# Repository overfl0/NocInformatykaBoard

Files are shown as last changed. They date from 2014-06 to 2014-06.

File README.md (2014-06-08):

Noc Informatyka Board
=====================

In this repository you'll find all the files related to the identifier given to every attendee of the Noc Informatyka^8 conference. You can find *[details]* here *(Polish)*.

This identifier was also a fully compatible Digispark clone.

Directories
===========

Schematics
----------

This directory holds the *[Eagle]* files used to create and produce the PCB for the identifier. The Eagle version that was used was 6.5.

Firmware
--------

This directory holds the micronucleus bootloader firmware that allows the badge to communicate with a PC and to upload sketches (programs) over the USB connector present on the board.

To upload a new firmware you either need to use an external HVSP programmer or use the virus-like firmware upgrade method.

#### Upload using an external HVSP programmer

Bear in mind that the microcontroller has its reset pin disabled. What this means is that regular ISP programmers (like USBasp) will not be able to program the board unless you reset the fuses with a HVSP programmer or something like *[Attiny fusebit Doctor]*.

```
make
make fuse
make flash
make disablereset
```

#### Upload using the virus-like method

This method has not been tested by us. **Use at your own risk!** See *upgrade* directory for details.

NocInformatyka2014
------------------

This directory holds the sketch preloaded on the badge. If for some reason you would like to revert to the original program, just upload this sketch to the board.

[eagle]:http://www.cadsoftusa.com/eagle-pcb-design-software/product-overview/?language=en
[attiny fusebit doctor]:http://www.instructables.com/id/AVR-Attiny-fusebit-doctor-HVSP/
[details]:http://nocinformatyka.pl/board/

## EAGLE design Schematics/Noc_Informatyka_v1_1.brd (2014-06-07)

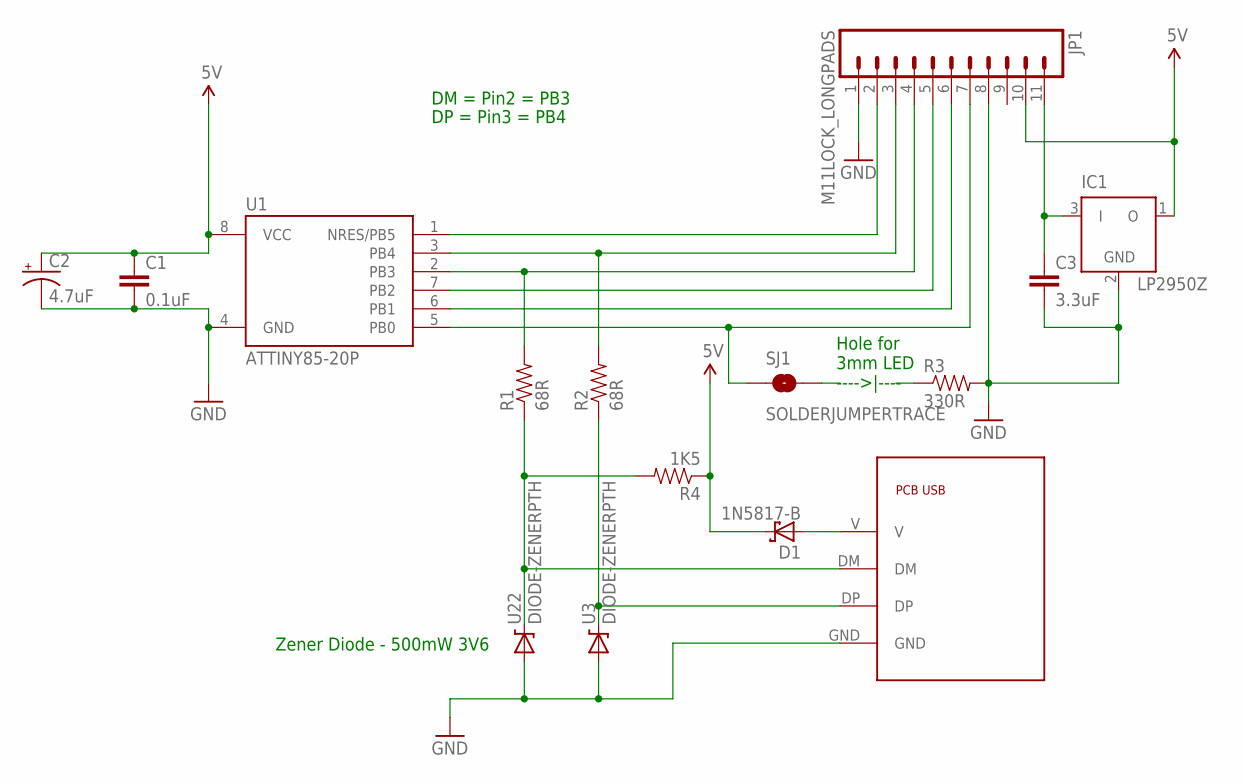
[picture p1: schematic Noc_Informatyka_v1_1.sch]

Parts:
C1: 0.1uF; CAP-PTH-SMALLEZ
C2: 4.7uF; CPOL-RADIAL-10UF-25V
C3: 3.3uF; CAP-PTH-5MM
D1: 1N5817-B; DO41-7.6
IC1: LP2950Z; TO92
JP1: M11LOCK_LONGPADS; 1X11_LOCK_LONGPADS
R1, R2: 68R; AXIAL-0.3EZ
R3: 330R; AXIAL-0.3EZ
R4: 1K5; AXIAL-0.3EZ
SJ1: SOLDERJUMPERTRACE; SJ_2S-TRACE
U1: ATTINY85-20P; PDIP08_300MIL
U3, U22: DIODE-ZENERPTH; DIODE-ZENER
U$1: PCB_USBNOBACK; PCB_USB

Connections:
5V: C1.1, C2.1 (+), D1.C, IC1.1 (O), JP1.10, R4.P$1 (1), U1.8 (VCC)
GND: C1.2, C2.2 (-), C3.2, IC1.2 (GND), JP1.1, JP1.8, R3.P$2 (2), U1.4 (GND), U3.P$2 (A), U22.P$2 (A), U$1.GND
unnamed: R1.P$1 (1), R4.P$2 (2), U22.P$1 (C), U$1.DM
unnamed: JP1.2, U1.1 (NRES/PB5)
unnamed: JP1.3, R2.P$2 (2), U1.3 (PB4)
unnamed: JP1.4, R1.P$2 (2), U1.2 (PB3)
unnamed: JP1.5, U1.7 (PB2)
unnamed: JP1.6, U1.6 (PB1)
unnamed: JP1.7, SJ1.1, U1.5 (PB0)
unnamed: C3.1, IC1.3 (I), JP1.11
unnamed: R2.P$1 (1), U3.P$1 (C), U$1.DP
unnamed: D1.A, U$1.V

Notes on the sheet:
DM = Pin2 = PB3
DP = Pin3 = PB4
Hole for 3mm LED ---->|----
Zener Diode - 500mW 3V6

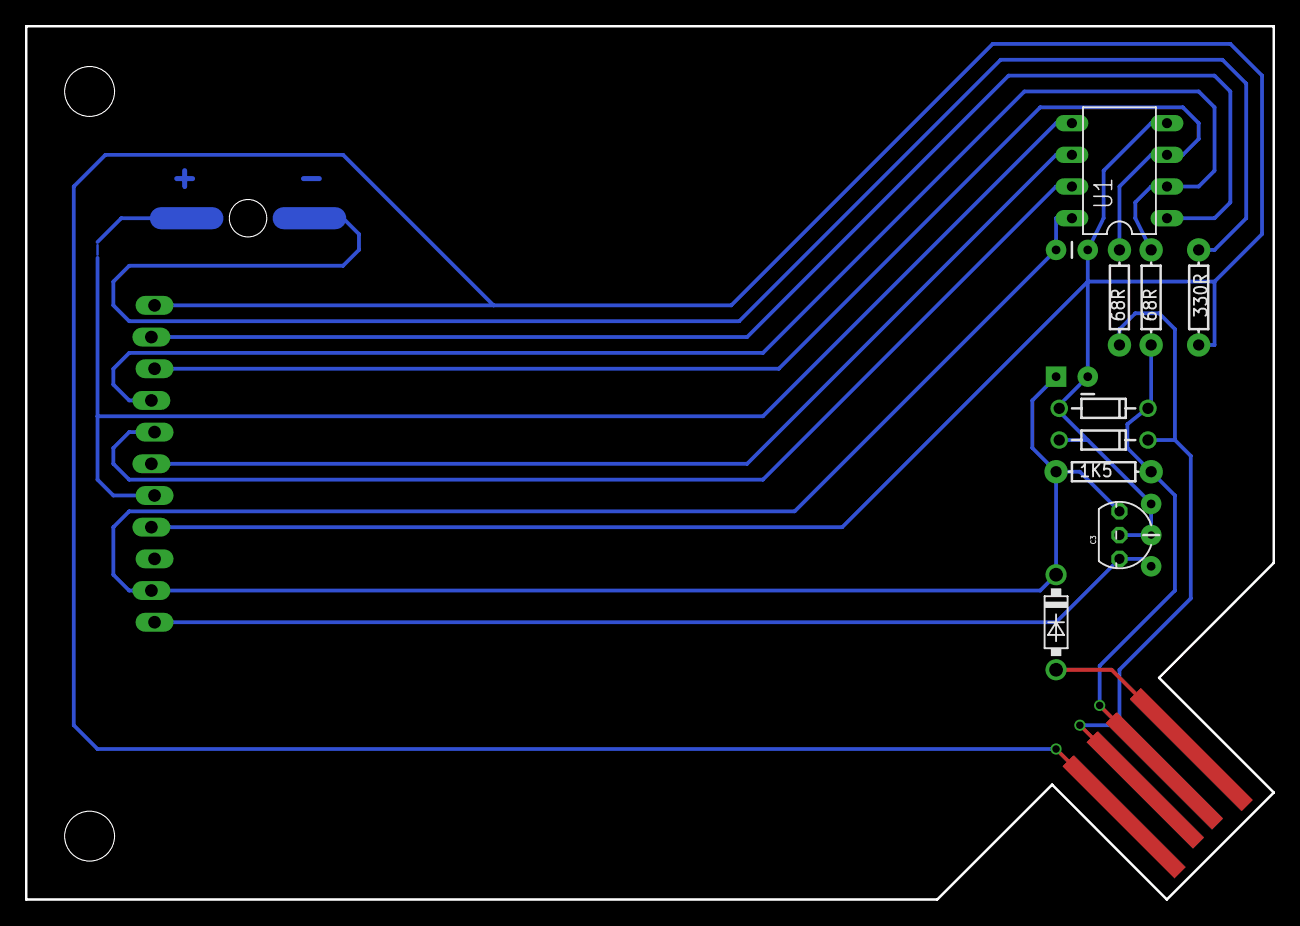
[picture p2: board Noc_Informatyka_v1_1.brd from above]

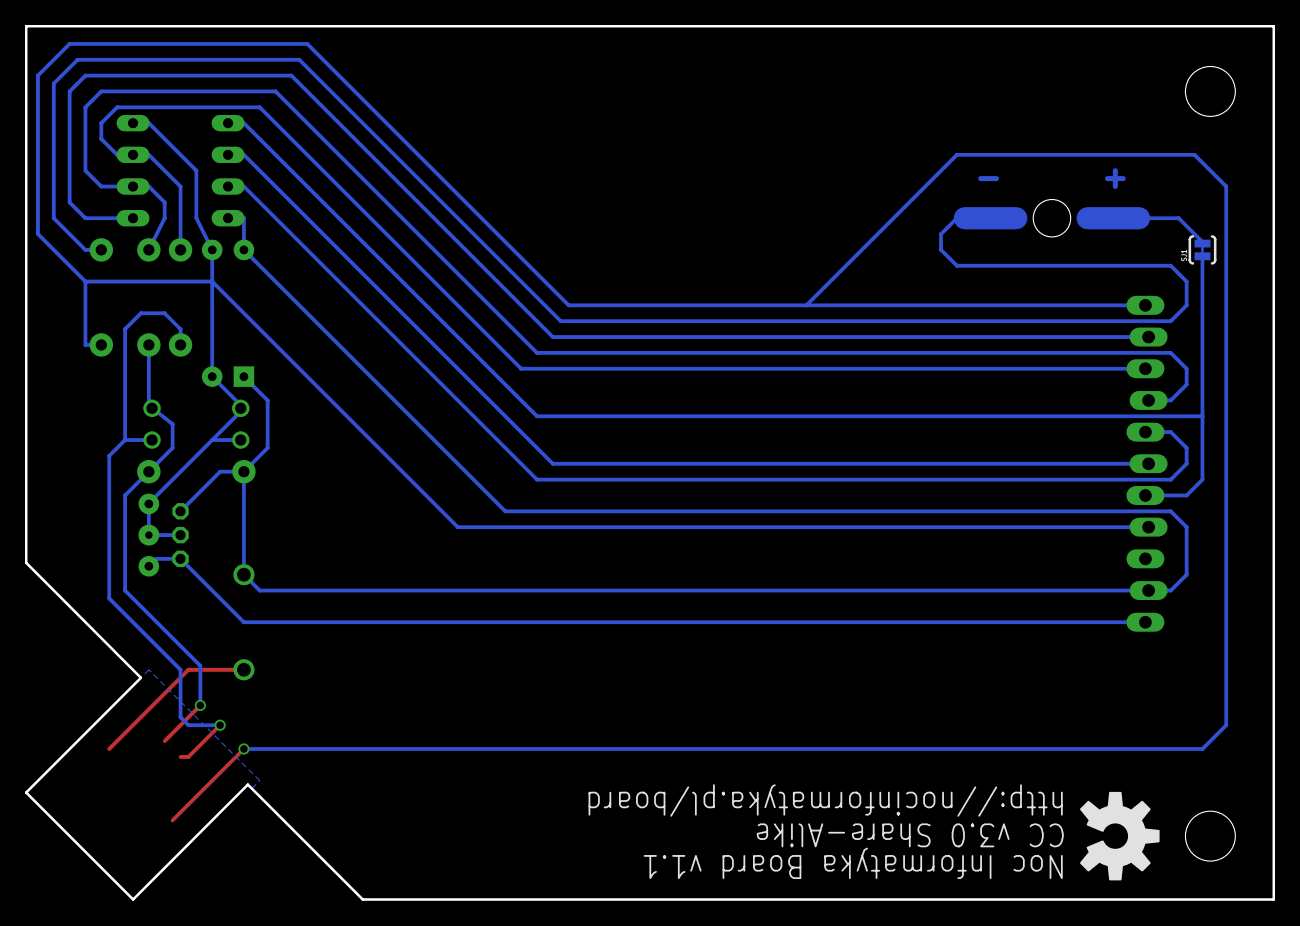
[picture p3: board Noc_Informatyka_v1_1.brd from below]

Board: 2 copper layers, 100.0 x 70.0 mm, 16 parts (2 on the bottom side), 12 nets.

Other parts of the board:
U$2: OSHW-LOGO-L

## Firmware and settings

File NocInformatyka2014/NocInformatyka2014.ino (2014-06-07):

/* Noc Informatyka 2014 program

Power usage:
Led turned on: 21.4 mA
Led turned off: 18.5 mA
*/

int led = 0;           // the pin that the LED is attached to
int brightness = 0;    // how bright the LED is
int fadeAmount = 1;    // how many points to fade the LED by
int showBrightness = 0;

void setup() {
  pinMode(led, OUTPUT);
}

void loop()  {
  // set the brightness of pin 0:
  showBrightness = brightness;
  if(showBrightness > 80)
    showBrightness = 80;

  if(showBrightness < 0)
    showBrightness = 0;
  analogWrite(led, showBrightness);

  // change the brightness for next time through the loop:
  brightness = brightness + fadeAmount;

  // reverse the direction of the fading at the ends of the fade:
  if (brightness == -50 || brightness == 128) {
    fadeAmount = -fadeAmount;
  }
  // wait for 30 milliseconds to see the dimming effect
  delay(100);
}

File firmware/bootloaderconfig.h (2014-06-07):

/* Name: bootloaderconfig.h
 * Project: USBaspLoader
 * Author: Christian Starkjohann
 * Creation Date: 2007-12-08
 * Tabsize: 4
 * Copyright: (c) 2007 by OBJECTIVE DEVELOPMENT Software GmbH
 * Portions Copyright: (c) 2012 Louis Beaudoin
 * License: GNU GPL v2 (see License.txt)
 * This Revision: $Id: bootloaderconfig.h 729 2009-03-20 09:03:58Z cs $
 */

#ifndef __bootloaderconfig_h_included__
#define __bootloaderconfig_h_included__

/*
 *  Bootloader defines
 */
 
#ifndef __ASSEMBLER__
  typedef union {
    uint16_t w;
    uint8_t b[2];
  } uint16_union_t;
#endif
/*
General Description:
This file (together with some settings in Makefile) configures the boot loader
according to the hardware.

This file contains (besides the hardware configuration normally found in
usbconfig.h) two functions or macros: bootLoaderInit() and
bootLoaderCondition(). Whether you implement them as macros or as static
inline functions is up to you, decide based on code size and convenience.

bootLoaderInit() is called as one of the first actions after reset. It should
be a minimum initialization of the hardware so that the boot loader condition
can be read. This will usually consist of activating a pull-up resistor for an
external jumper which selects boot loader mode.

bootLoaderCondition() is called immediately after initialization and in each
main loop iteration. If it returns TRUE, the boot loader will be active. If it
returns FALSE, the boot loader jumps to address 0 (the loaded application)
immediately.

For compatibility with Thomas Fischl's avrusbboot, we also support the macro
names BOOTLOADER_INIT and BOOTLOADER_CONDITION for this functionality. If
these macros are defined, the boot loader uses them.
*/

#define TINY85_HARDWARE_CONFIG_1  1
#define TINY85_HARDWARE_CONFIG_2  2

/* ---------------------------- Hardware Config ---------------------------- */
#define HARDWARE_CONFIG     TINY85_HARDWARE_CONFIG_2

#define USB_CFG_IOPORTNAME      B
  /* This is the port where the USB bus is connected. When you configure it to
   * "B", the registers PORTB, PINB and DDRB will be used.
   */

#ifndef __AVR_ATtiny85__
  # define USB_CFG_DMINUS_BIT      0
  /* This is the bit number in USB_CFG_IOPORT where the USB D- line is connected.
   * This may be any bit in the port.
   */
  #define USB_CFG_DPLUS_BIT       2
  /* This is the bit number in USB_CFG_IOPORT where the USB D+ line is connected.
   * This may be any bit in the port. Please note that D+ must also be connected
   * to interrupt pin INT0!
   */
#endif
 
#if (defined __AVR_ATtiny85__) && (HARDWARE_CONFIG == TINY85_HARDWARE_CONFIG_1)
  #define USB_CFG_DMINUS_BIT      0
  /* This is the bit number in USB_CFG_IOPORT where the USB D- line is connected.
   * This may be any bit in the port.
   */
  #define USB_CFG_DPLUS_BIT       2
  /* This is the bit number in USB_CFG_IOPORT where the USB D+ line is connected.
   * This may be any bit in the port, but must be configured as a pin change interrupt.
   */
#endif
 
#if (defined __AVR_ATtiny85__) && (HARDWARE_CONFIG == TINY85_HARDWARE_CONFIG_2)
#define USB_CFG_DMINUS_BIT      3
/* This is the bit number in USB_CFG_IOPORT where the USB D- line is connected.
 * This may be any bit in the port.
 */
#define USB_CFG_DPLUS_BIT       4
/* This is the bit number in USB_CFG_IOPORT where the USB D+ line is connected.
 * This may be any bit in the port, but must be configured as a pin change interrupt.
 */
#endif

#define USB_CFG_CLOCK_KHZ       (F_CPU/1000)
/* Clock rate of the AVR in kHz. Legal values are 12000, 16000 or 16500.
 * The 16.5 MHz version of the code requires no crystal, it tolerates +/- 1%
 * deviation from the nominal frequency. All other rates require a precision
 * of 2000 ppm and thus a crystal!
 * Default if not specified: 12 MHz
 */

/* ----------------------- Optional Hardware Config ------------------------ */

/* #define USB_CFG_PULLUP_IOPORTNAME   D */
/* If you connect the 1.5k pullup resistor from D- to a port pin instead of
 * V+, you can connect and disconnect the device from firmware by calling
 * the macros usbDeviceConnect() and usbDeviceDisconnect() (see usbdrv.h).
 * This constant defines the port on which the pullup resistor is connected.
 */
/* #define USB_CFG_PULLUP_BIT          4 */
/* This constant defines the bit number in USB_CFG_PULLUP_IOPORT (defined
 * above) where the 1.5k pullup resistor is connected. See description
 * above for details.
 */

/* ------------------------------------------------------------------------- */
/* ---------------------- feature / code size options ---------------------- */
/* ------------------------------------------------------------------------- */
 
/* ----------------------- Optional MCU Description ------------------------ */

/* tiny85 Architecture Specifics */
#ifndef __AVR_ATtiny85__
#  error "uBoot is only designed for attiny85"
#endif
#define TINY85MODE

/* ------------- Set up interrupt configuration (CPU specific) -------------- */
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

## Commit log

2014-06-07 Changed microcontroller fuses (brownout protection set to 4.5V) Changed bootloader timeout from 5 to 3 seconds
    [bootloaderconfig.h]
2014-06-07 Added the program that was originally uploaded to the board the day of the conference
2014-06-07 Added Noc Informatyka Board schematics
    [Noc_Informatyka_v1_1.brd, Noc_Informatyka_v1_1.sch]

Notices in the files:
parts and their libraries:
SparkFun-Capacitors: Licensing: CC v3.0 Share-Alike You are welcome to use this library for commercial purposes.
